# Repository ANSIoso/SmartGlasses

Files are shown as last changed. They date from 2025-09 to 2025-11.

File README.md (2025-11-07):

# SmartGlasses
Simple prototype of AR glasses inspired to Dragon Ball scouter and powered by Esp32 - cam and YOLO11
<p align="center"  style="display: flex; gap: 50px; justify-content: center;">
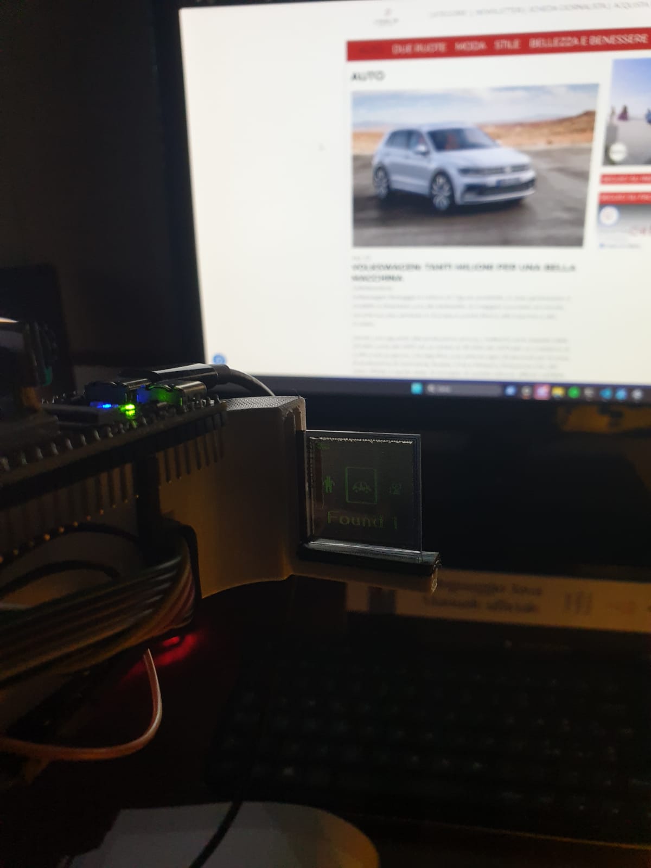
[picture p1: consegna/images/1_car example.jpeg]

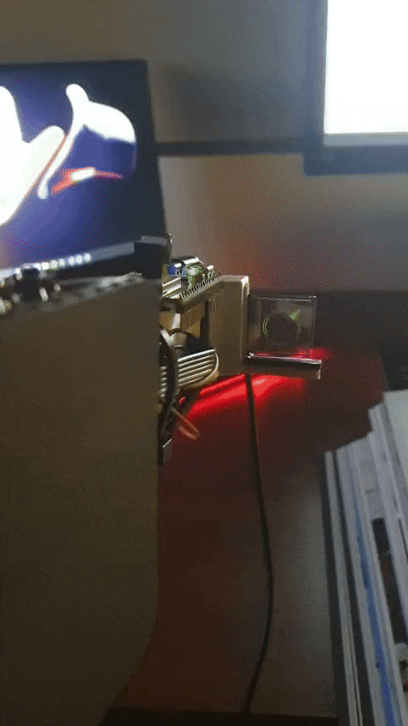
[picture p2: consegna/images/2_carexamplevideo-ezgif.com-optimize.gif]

</p>

<p align="center">
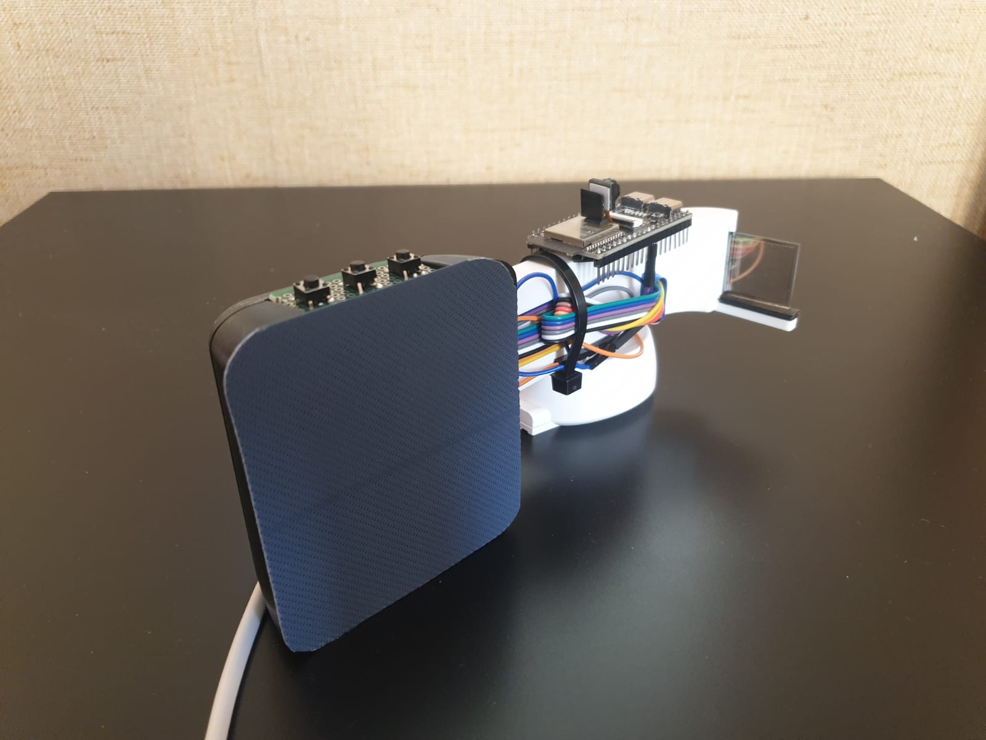
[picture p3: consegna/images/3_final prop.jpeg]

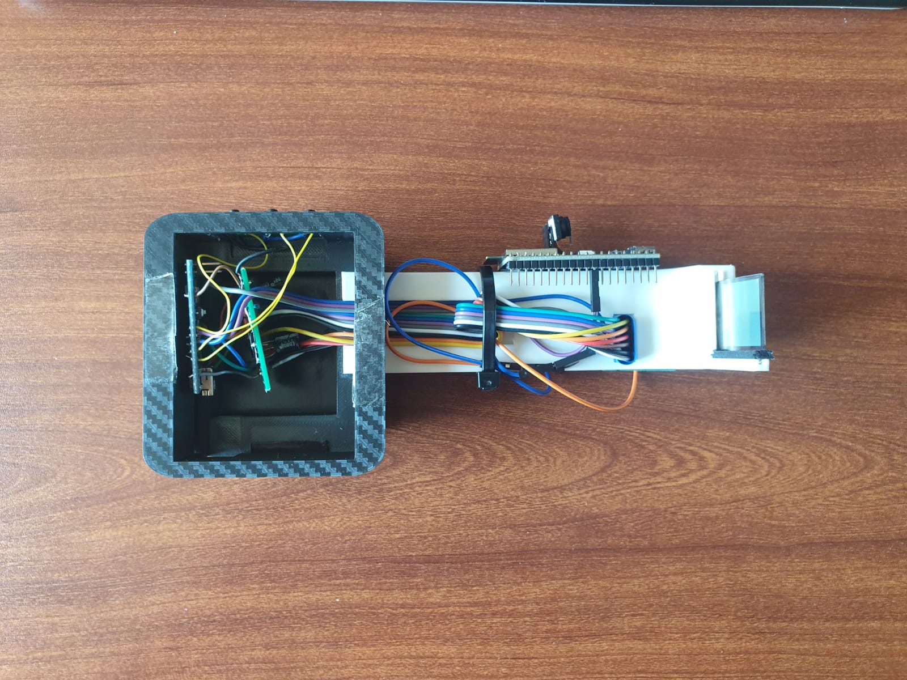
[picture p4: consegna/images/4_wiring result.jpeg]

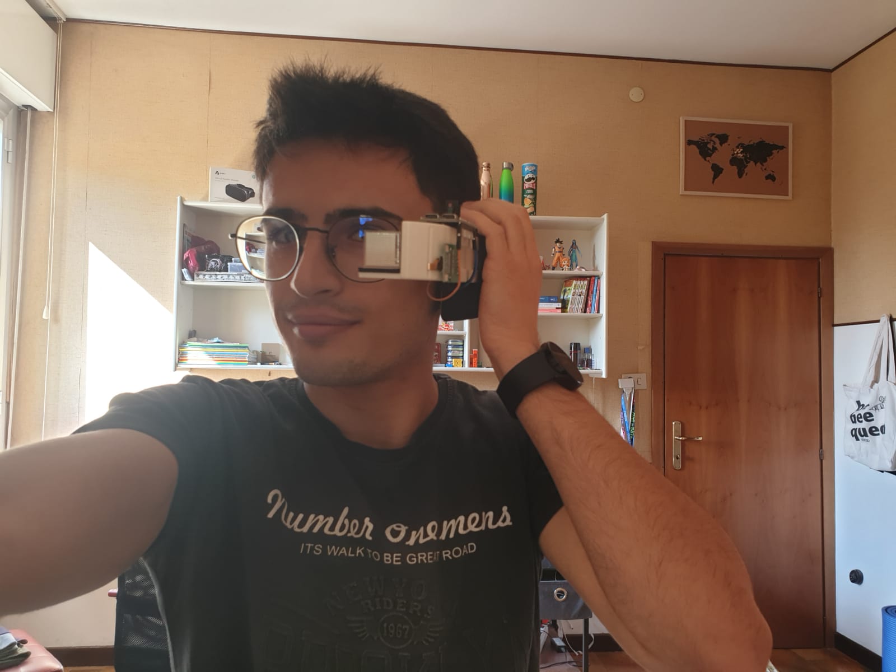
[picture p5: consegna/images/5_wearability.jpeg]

</p>

## Requirements

- hardware
    - [ESP32-S3 WROOM N16R8 CAM](https://it.aliexpress.com/item/1005007308040075.html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)
    - [Arduino Nano 3.0](https://it.aliexpress.com/item/1005008505441191.html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)
    - [Transparent OLED Display](https://it.aliexpress.com/item/1005007983700262.html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)
    - Your PC

- software requirements
    - [ultralitics yolo11](https://docs.ultralytics.com/quickstart/)
    - [ArduinoJson](https://arduinojson.org/v6/doc/installation/)
    - [U8g2lib](https://github.com/olikraus/u8g2/wiki/u8g2install)

## how it works

<p><strong>Pipeline</strong></p>

The sistem uses 3 distict elements to work, the ESP32 who capture the image and coordinate all the operations, the pc who process the image recevived by the esp32 using the yolo11 model and pacs the information about the received object for a easier use in the rest of the pipeline and the arduino nano that takes the info received and display it in the trasparent dispaly.

<p align="center">
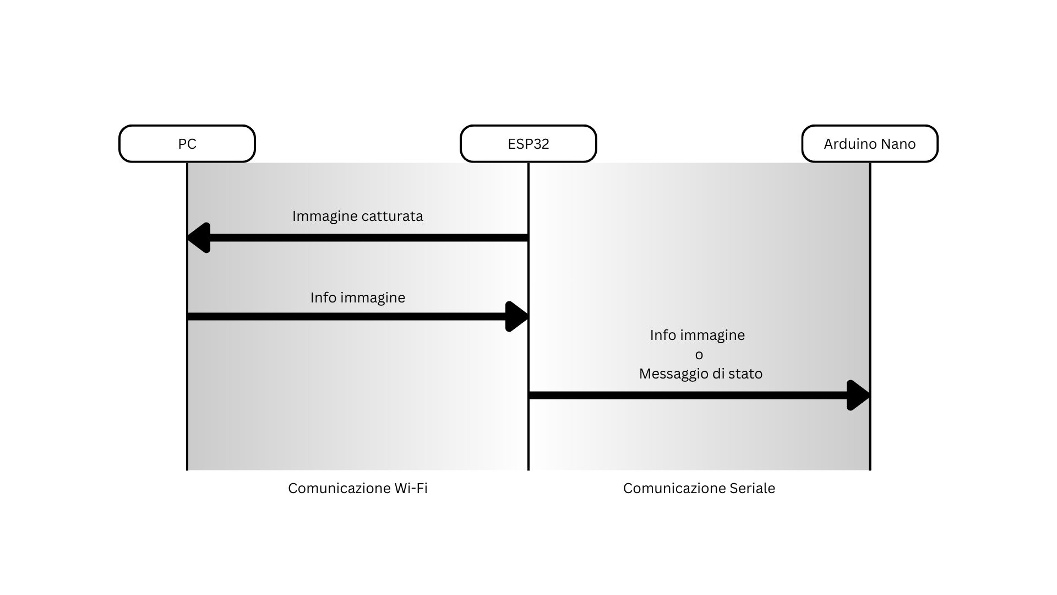
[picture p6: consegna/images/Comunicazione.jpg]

</p>

<p><strong>Interface</strong></p>

The information about the detected object is shown on the trasparent screeen, is possible to visualize the information in two different format:
- the **count view** that show the selected object category and the number of occorrence 
- the **radar view** that show the position of the detected objects for the selected category

<p align="center" style="display: flex; gap: 50px; justify-content: center;">
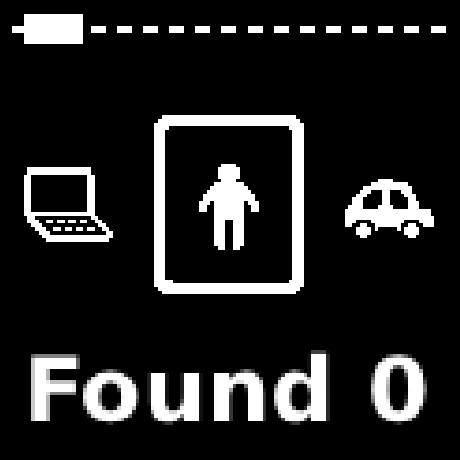
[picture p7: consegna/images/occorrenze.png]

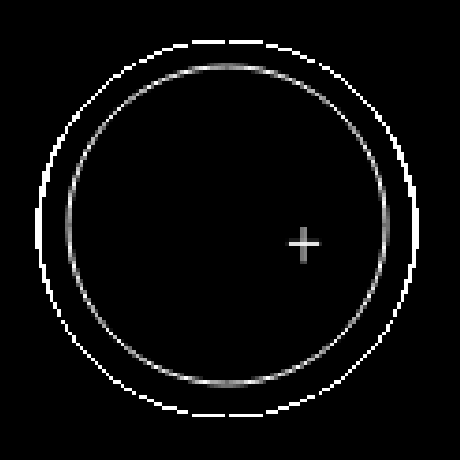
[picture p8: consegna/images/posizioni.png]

</p>

In order to create the radar view the detected position are first converted to the size of the screen, then to add the arrow effect the distance from the center of the screen is calculated, if the resulting distance is greeater than a certain tresholde the position are scomposed to sin and cos respect a reference sistem positioned in the center of the screen, this are used to find the angle at wich dispaly the arrow

Two of the buttons on the device are used to go back and forth betwen the category and the other to swithch betwen the views
<p align="center">
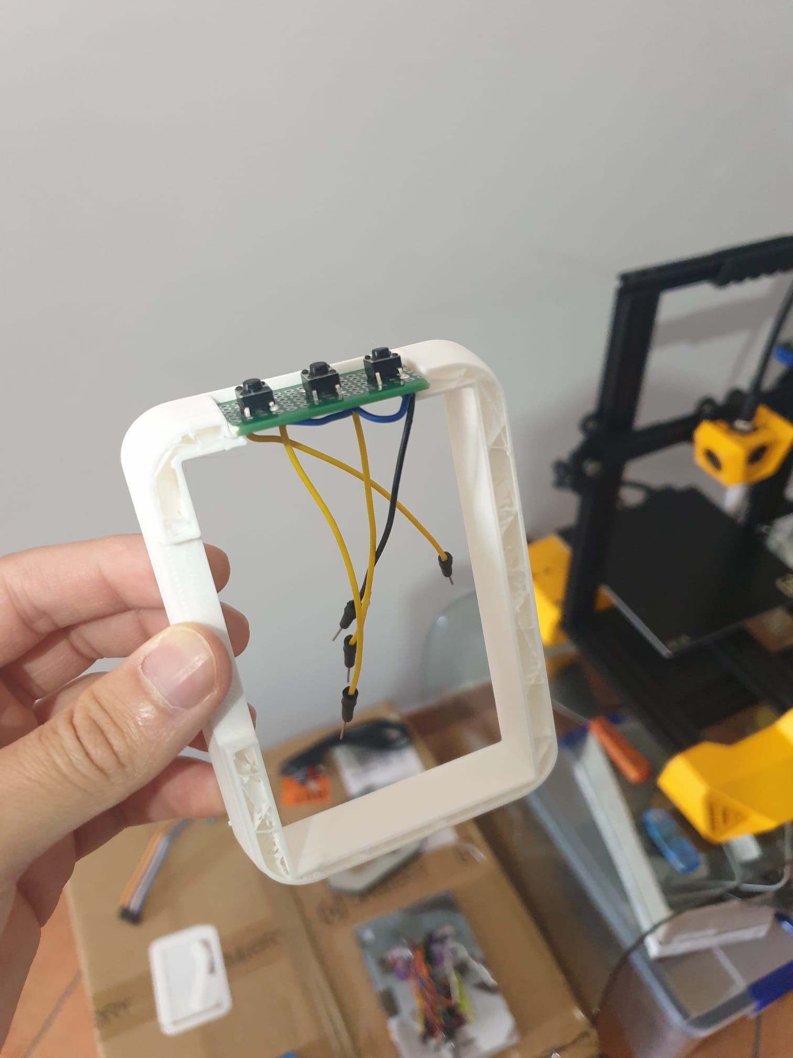
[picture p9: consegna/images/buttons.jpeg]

</p>

## Wiring
<p align="center">
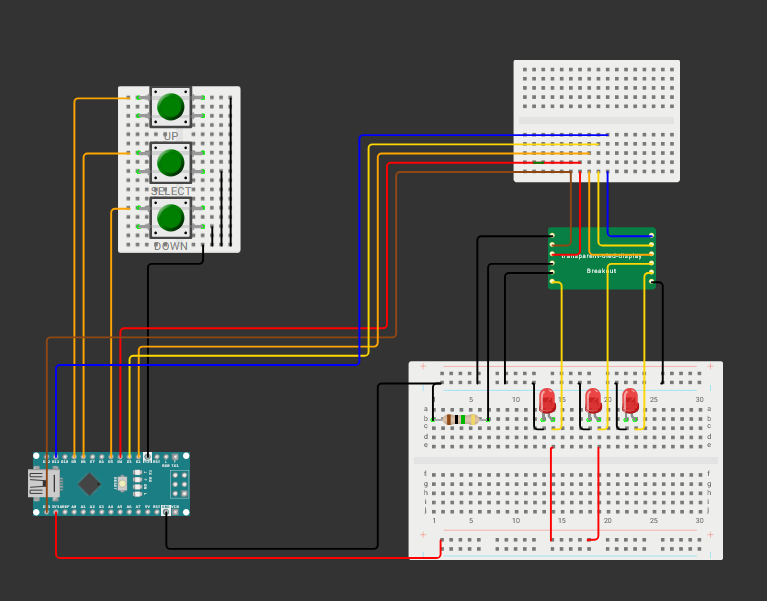
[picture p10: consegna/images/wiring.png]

</p>

For detailed wiring of the display board, refer to the [official screen documentation](https://surenoo.tech/download/03_SOL/0302_SOG/SOG128128A_T112.pdf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) (note: the LEDs in the schematic represent 10㎌ 50V capacitors).

To complete the circuit, establish serial communication between the Arduino and ESP32:
- Connect the grounds between the two boards
- Connect RX to TX (pin 6 on Arduino, pin 1 on ESP32)
- Connect TX to RX (pin 7 on Arduino, pin 3 on ESP32)

## 3D print

All the components are contained in a case to emulate the famus Scouter from Dragon Ball Z, to reproduce it I started from [this model 3D model](https://www.thingiverse.com/thing:2853831) that i found online and edited it in fusion 360 to make room for all the components. The result models are contained in the folder [glasses_assets/3D model](./glasses_assets/3D%20model/)

- [Asta.stl](./glasses_assets/3D%20model/Asta.stl) that holds the trasparent dispaly and the ESP32
- [Coperchio.stl](./glasses_assets/3D%20model/Coperchio.stl) that contains the Arduino Nano and the display board
- [Padiglione.stl](./glasses_assets/3D%20model/Padiglione.stl) that holds the buttons

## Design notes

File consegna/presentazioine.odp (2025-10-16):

## Scouter DAI

Augmented Reality Glasses

## Obiettivi del Progetto

  Sviluppare un dispositivo :
  - Indossabile e autonomo
  - Capace di analizzare l’ambiente circostante in tempo reale
  - Il cui restituisce informazioni utili e contestuali direttamente all’utente

## Ispirazione Scouter DAI

- Dispositivo indossabile
- Analisi in tempo reale di ciò che si ha di fronte, per supportare l’utente
- Informazioni visive tramite display trasparente

## Architettura del Dispositivo AR

- Acquisizione dati:
  estrapolazione di informazioni dall’ambiente tramite
- Visualizzazione:
  proiezione su schermo trasparente

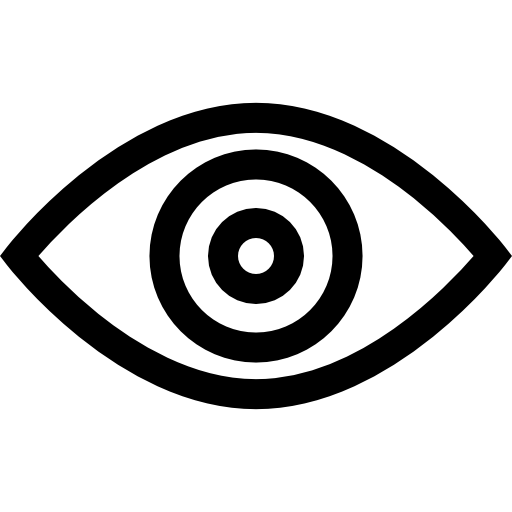
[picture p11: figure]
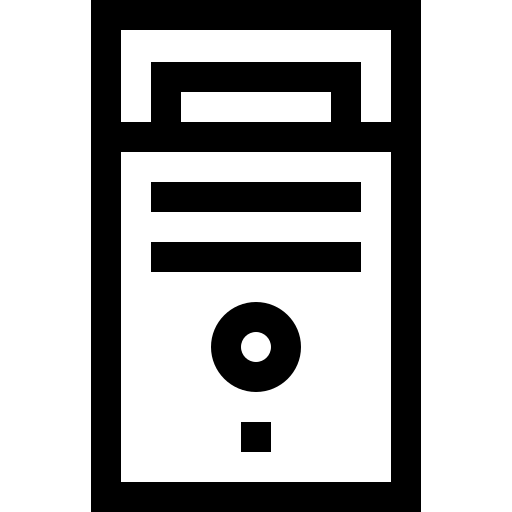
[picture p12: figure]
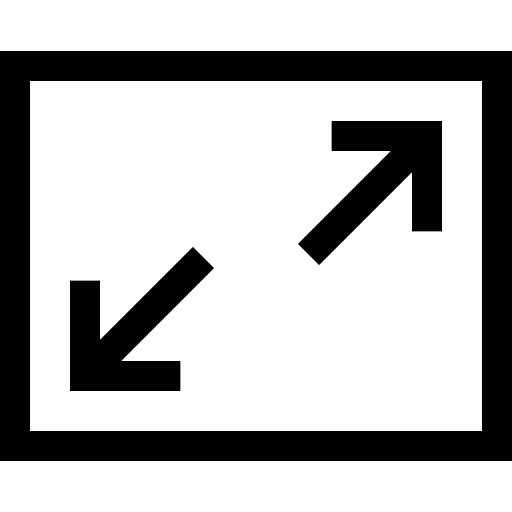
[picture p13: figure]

- Elaborazione:
  analisi delle immagini

## Analisi delle Immagini

  L’analisi delle immagini viene realizzata tramite tecniche di object detection
- Approccio Edge:
  - Esecuzione direttamente sul dispositivo
  - Librerie: Edge Impulse, TensorFlow Lite
- Approccio Client-Server:
  - Elaborazione delle immagini su “supporti” esterni
  - Modelli avanzati: Faster R-CNN, YOLO v11

## Pipeline Elaborazione AR

1) Acquisizione:

l’ESP32-CAM cattura singole immagini

2) Trasmissione:

invio delle immagini al PC tramite HTTP

3) Elaborazione:

il PC analizza le immagini con YOLO v11 individua oggetti e categorie

4) Restituzione dati:

il PC invia i risultati in formato JSON all’ESP32

5) Comunicazione interna:

l’ESP32 condivide i dati con l’Arduino Nano tramite seriale

6) Visualizzazione:

l’Arduino mostra a schermo la posizione degli oggetti rilevati

## Hardware Utilizzato

  Il sistema integra dispositivi eterogenei, ognuno con un ruolo specifico
- ESP32-S3 WROOM N16R8 CAM
  - Raccolta delle immagini dall’ambiente
  - Coordinamento e arbitraggio tra i componenti
- Arduino Nano 3.0
  - Visualizzazione delle informazioni sullo schermo trasparente
  - Gestione Input tasti
- PC
  - Elaborazione delle immagini tramite modelli di Object Detection

## Hardware Utilizzato

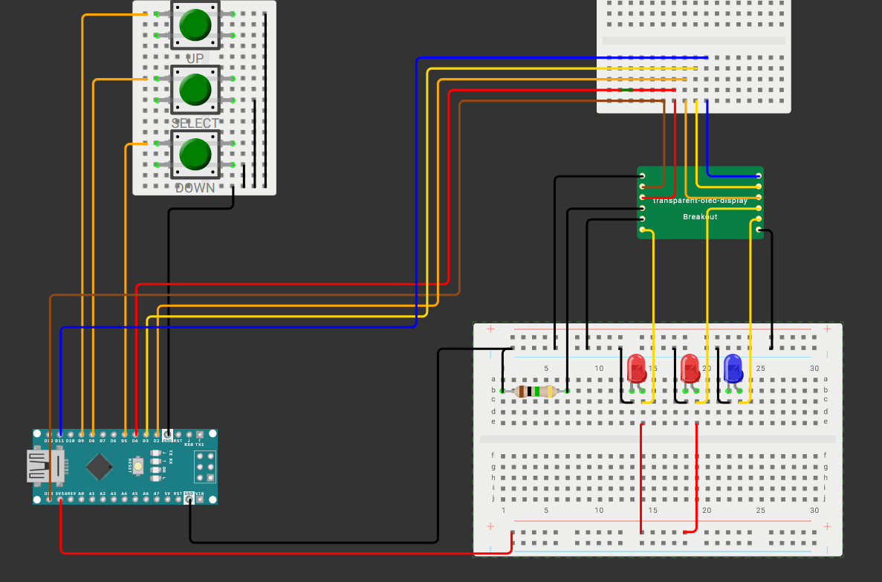
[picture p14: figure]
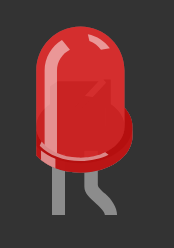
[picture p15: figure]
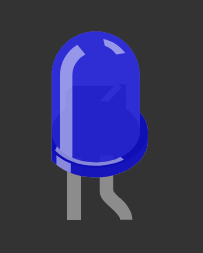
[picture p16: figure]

Condensatore

Condensatore

Resistenza

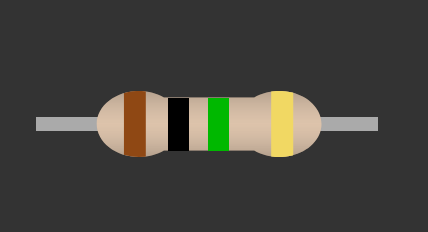
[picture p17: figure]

## Assemblaggio

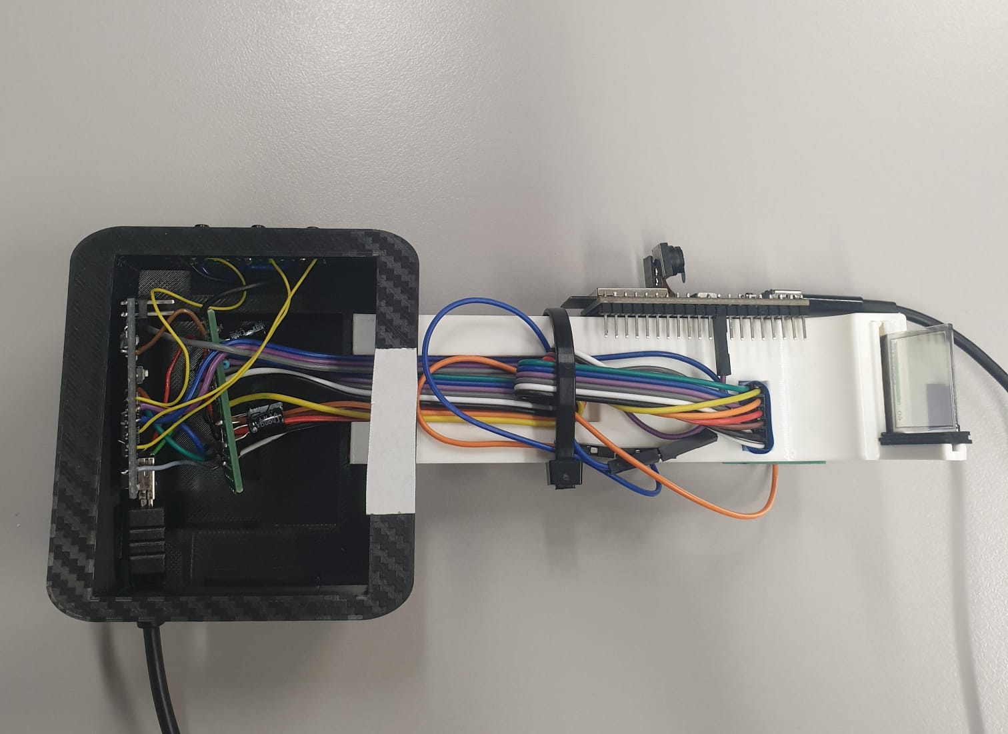
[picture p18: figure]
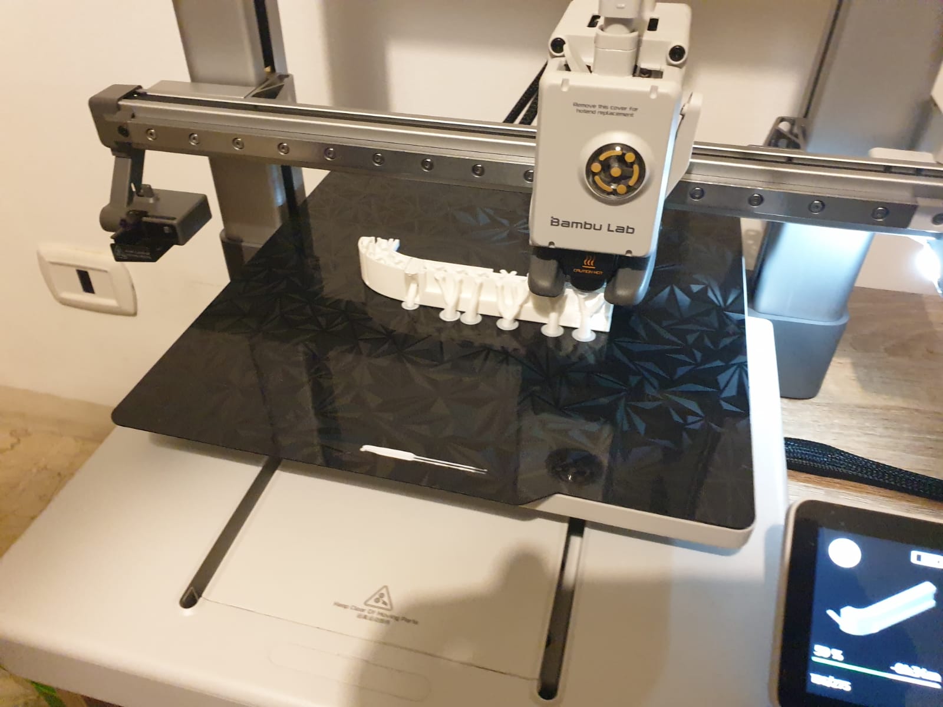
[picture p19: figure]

Condensatore

Condensatore

Resistenza

## Elaborazione Immagini

Object Detection Effettuata

con YOLO v11

Comunicazione ESP32 ↔ PC:

- ESP32 → invio tramite HTTPClient
- PC → gestione richieste con Flask

Debug e visualizzazione dei risultati tramite OpenCV (cv2)

## Visualizzazione Informazioni

La pipeline di visualizzazione traduce i dati elaborati in informazioni grafiche comprensibili e immediatamente fruibili dall’utente.

I dati in formato JSON ricevuti dall’ESP32 vengono inviati ad Arduino Nano tramite comunicazione seriale

L’Arduino spacchetta i dati e li mostra sullo schermo trasparente

Visualizzazione implementata con:

- ArduinoJson → parsing dei dati
- U8g2 → gestione delle primitive grafiche e bitmap

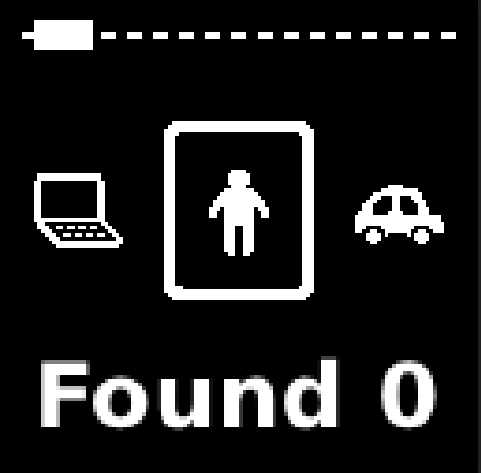
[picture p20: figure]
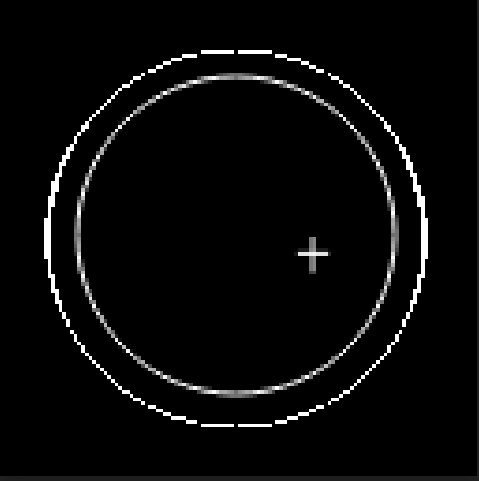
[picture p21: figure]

## Problemi Riscontrati (Schede)

- Compatibilità ESP32-S3 CAM
  - Complessità utilizzo libreria U8g2
  - Problemi con alcune librerie di Machine Learning (Edge Impulse)
- Capienza Arduino Nano
  - Memoria limitata per gestione dei dati e visualizzazione
- Latenza del sistema
  - Tempi di cattura della camera
  - Comunicazione con il server per l’elaborazione

## Problemi Riscontrati (Display)

- Disponibilità delle informazioni:
  - Gestione del wiring tra componenti
  - Utilizzo corretto delle librerie per parsing e rendering dei dati
- Visualizzazione delle informazioni:
  - Alta densità di informazioni su schermo di piccole dimensioni
  - Problemi di messa a fuoco dovuti alla distanza dagli occhi

## Pro e Contro del Sistema

Il sistema offre grande flessibilità, ma richiede compromessi su performance e visualizzazione.

- Pro modularità:
  - Possibilità di sostituire modelli di analisi e interfacce utente
  - Flessibilità nella rappresentazione dei dati all’utente
- Contro:
  - Tempi di latenza dovuti a acquisizione immagini e comunicazione con server
  - Dimensioni totali

## Conclusioni

Il progetto offre una base solida per dispositivi AR indossabili, con margini di miglioramento per portabilità e ottimizzazione hardware.

Possibili sviluppi futuri:

- Ridurre le dimensioni complessive utilizzando schede dedicate
- Spostare l’elaborazione per aumentare la portabilità:
  - Su smartphone
  - Su edge devices

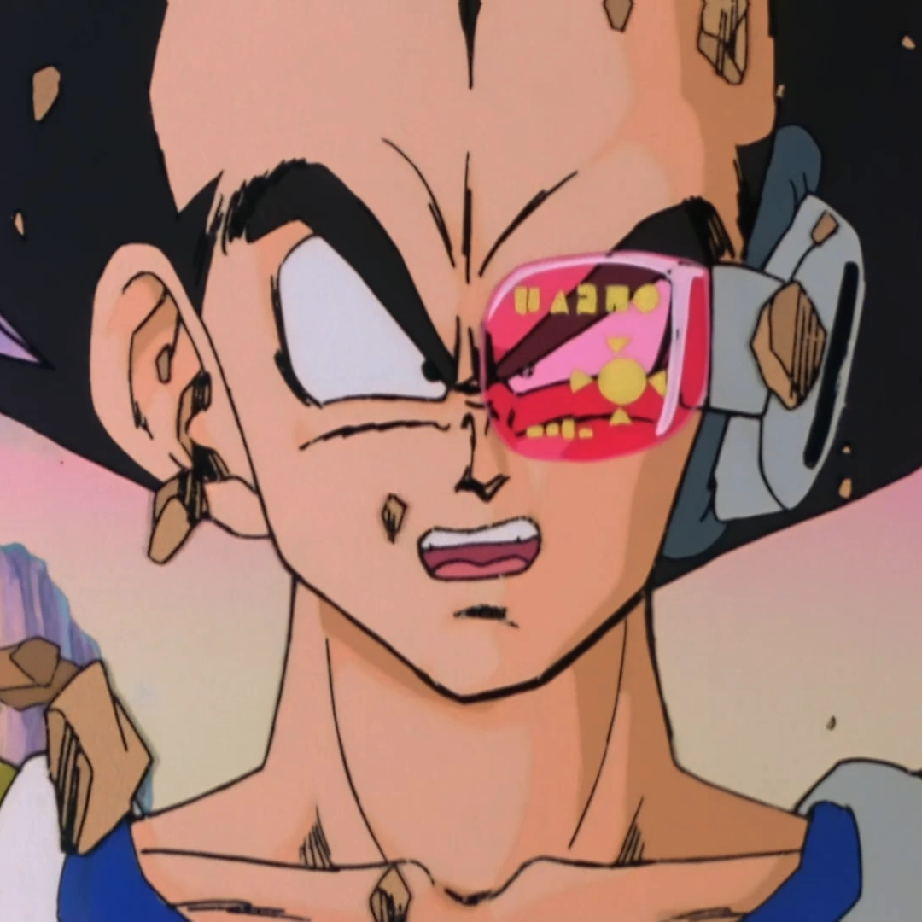
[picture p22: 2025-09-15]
consegna/images/Scouter_Reference.png

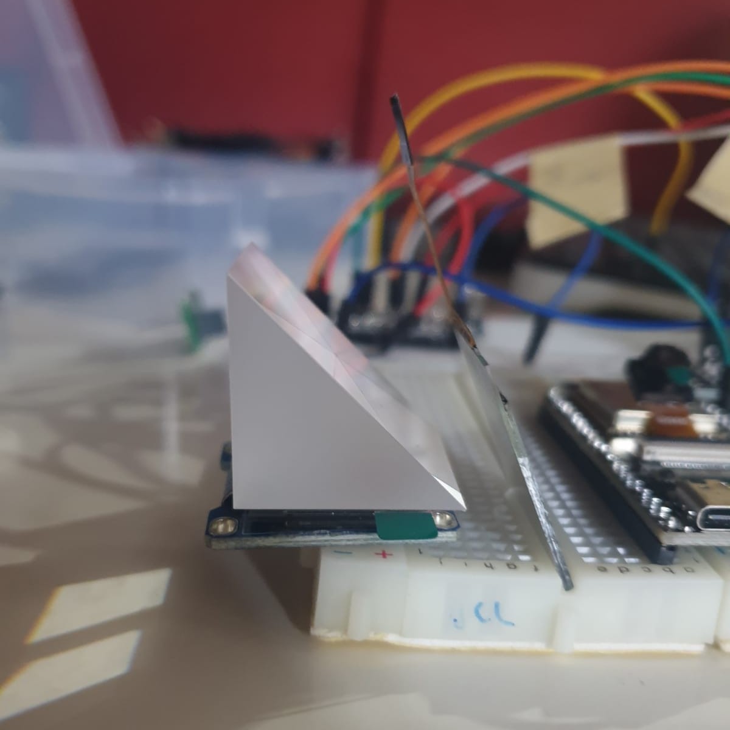
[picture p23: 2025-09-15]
consegna/images/screen_comp1.jpeg

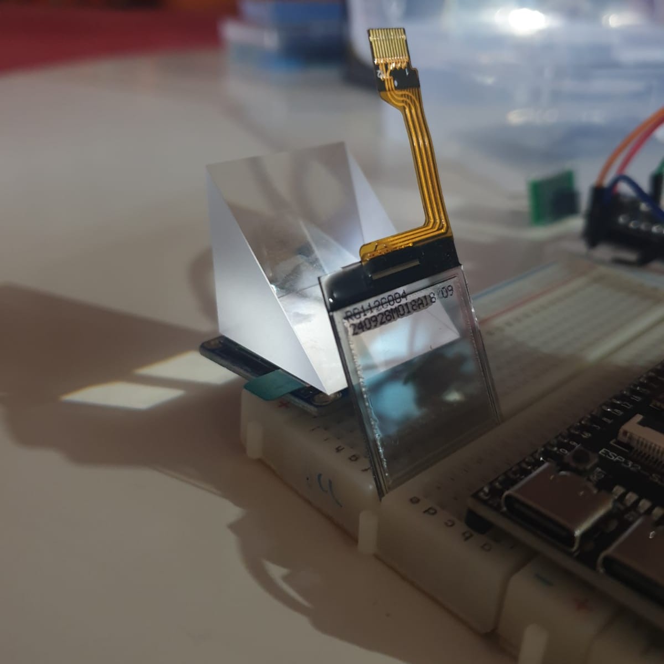
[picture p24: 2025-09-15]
consegna/images/screen_comp2.jpeg

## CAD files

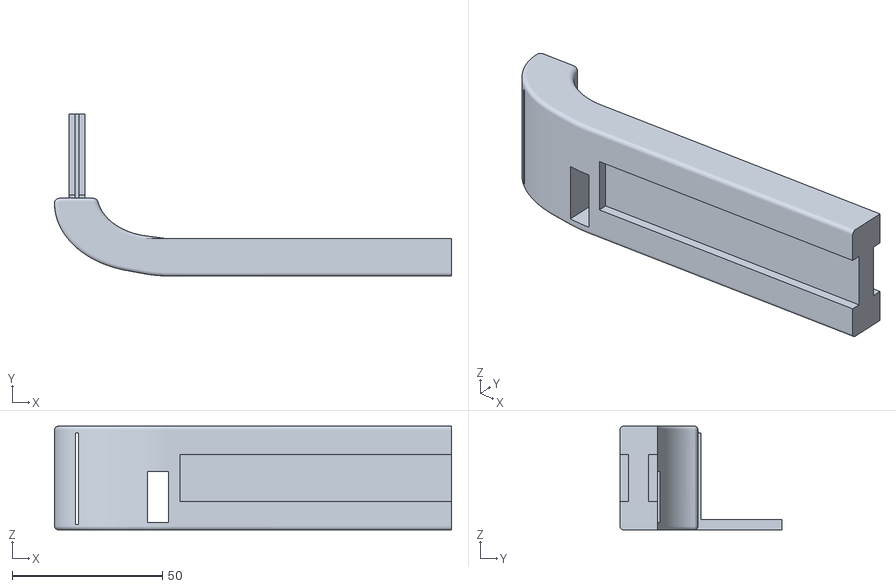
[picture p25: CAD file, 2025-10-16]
glasses_assets/3D model/Asta.stl
132.2 x 53.9 x 34.6

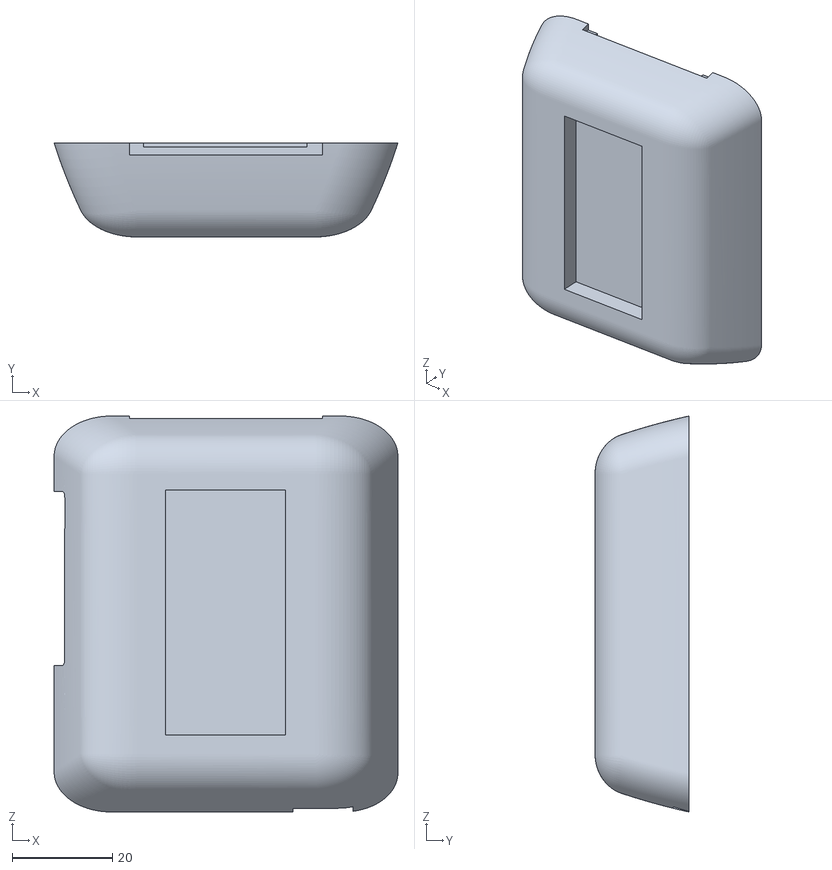
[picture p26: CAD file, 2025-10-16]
glasses_assets/3D model/Coperchio.stl
68.5 x 18.7 x 78.9

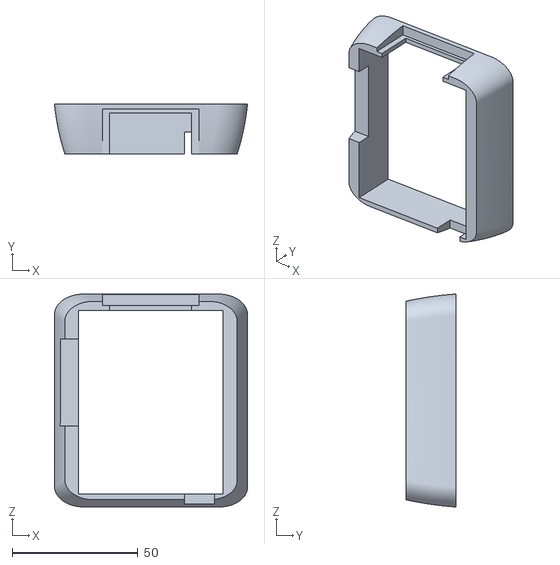
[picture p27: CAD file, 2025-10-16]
glasses_assets/3D model/Padiglione.stl
76.7 x 19.9 x 84.6

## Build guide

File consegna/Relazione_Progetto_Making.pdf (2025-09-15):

# Relazione Progetto Making

Antonio Sisinni

Septembre 2025

## 1 Introduzione

L’obiettivo del progetto `e quello di mettere in pratica le conoscenze acquisite durante le lezioni, in particolare riguardo a:

- schede programmabili
- sensori e interruttori
- circuiti elettrici
- stampa 3D

Tali competenze devono essere applicate per realizzare un prototipo funzionante, in grado di svolgere un compito da noi definito.

## 2 Idea

L’idea alla base del progetto consiste nello sviluppo di un dispositivo in grado di integrare diverse tecnologie affrontate a lezione, con l’aggiunta di elementi di interesse personale. A tale scopo ho deciso di realizzare un dispositivo indossabile per la realt`a aumentata.

Il sistema prevede l’impiego di una telecamera per acquisire informazioni dall’ambiente circostante. I dati raccolti vengono elaborati e successivamente presentati all’utente tramite un display trasparente, cos`ı da non compromettere la visibilit`a diretta.

L’interazione con il dispositivo `e resa possibile attraverso dei pulsanti che consentono all’utente di filtrare o modificare le informazioni visualizzate.

Data la necessit`a di includere pi`u componenti hardware, il design di riferimento scelto `e lo scouter della serie Dragon Ball. Esso presenta dimensioni adeguate per ospitare i vari elementi, garantendo al contempo una buona ergonomia.

1

## 3 Studio di fattibilit`a

### 3.1 Schermo trasparente

In un primo momento avevo pensato di utilizzare un normale schermo abbinato a un prisma ottico, cos`ı da ridirezionare l’immagine e permettere all’utente di guardare attraverso.

Sebbene questa soluzione fosse funzionale, l’ingombro complessivo e il peso derivante dall’accoppiata schermo + prisma mi hanno spinto a optare per l’utilizzo di un display trasparente Figura 1.

Questa scelta, tuttavia, ha introdotto una nuova difficolt`a: la libreria u8g2 (utilizzata per disegnare sul display), il mio specifico display e la scheda ESP32-S3, non risultavano funzionanti assieme.

Per superare questo problema ho adottato una configurazione ibrida: la ESP32-S3 per la potenza di elaborazione, affiancata da un Arduino Nano dedicato esclusivamente alla gestione della visualizzazione sul display.


Figure 1: Confronto ingombri tra le due soluzioni per il display schermo

### 3.2 Elaborazione delle immagini

La mia idea iniziale era di sfruttare direttamente la ESP32-S3 per l’elaborazione delle immagini, in quanto dotata di capacit`a di calcolo sufficienti a supportare modelli di machine learning leggeri (soluzioni come edgeimpulse o tensorflow lite nascono proprio per dispositivi del genere).

Tuttavia, la scheda da me acquistata presentava scarsa documentazione e non aveva compatibilit`a diretta con librerie apposite. Dopo alcuni tentativi ho quindi

2

deciso di utilizzare la ESP32-S3 unicamente la cattura dei dati e la trasmissione di essi via Wi-Fi, demandando l’elaborazione delle immagini a un dispositivo esterno. In questo modo ho potuto ottenere le informazioni necessarie mantenendo il dispositivo portatile.

## 4 Struttura del Sistema

Le diverse parti del sistema collaborano per assolvere compiti distinti, cos`ı da garantire il corretto funzionamento complessivo e la fruibilit`a da parte dell’utente.

- ESP32-s3 cuore del sistema, si occupa di acquisire le immagini e di gestire la comunicazione tra le varie componenti
- Arduino Nano gestisce il display OLED trasparente sul quale l’utente visualizza le informazioni elaborate. Inoltre, si occupa dell’acquisizione degli input dell’utente
- Un PC `e usato come dispositivo esterno per eseguire l’elaborazione delle immagini tramite il modello di computer vision YOLOv11, che consente di individuare all’interno di immagini oggetti presenti, identificandone posizione e classe di appartenenza.

## 5 Pipeline di Comunicazione

Affinch´e il sistema possa operare correttamente, le diverse componenti devono comunicare tra loro. La struttura della comunicazione `e illustrata in Figura 2.

La connessione tra l’esp32-s3 e il PC avviene in modalit`a wireless, cos`ı da garantire la mobilit`a dell’utente. La comunicazione tra l’esp32-s3 e l’Arduino Nano, invece, utilizza un semplice collegamento seriale, per garantire bassa latenza.

### 5.1 Messaggi di Stato

Oltre a trasmettere le informazioni relative alle immagini acquisite, l’esp32-s3 pu`o inviare una serie di messaggi sullo stato del sistema. Questi messaggi risultano particolarmente utili per informare l’utente sul corretto funzionamento del dispositivo, soprattutto in caso di malfunzionamenti nella trasmissione dei dati.

I messaggi di stato previsti sono:

- connecting: indica che il dispositivo sta tentando di stabilire la connessione con il PC
- com err: segnala un problema di comunicazione tra l’esp32-s3 e il PC

3


Figure 2: Schema della pipeline di comunicazione tra le componenti del sistema.

## 6 Hardware Utilizzato

### 6.1 Componenti

Per la realizzazione del prototipo ho utilizzato i seguenti componenti:

- ESP32-S3 WROOM N16R8 CAM (https://it.aliexpress.com/item/1005007308040075.html)
- Arduino Nano 3.0 (https://it.aliexpress.com/item/1005008505441191.html)
- Display OLED Trasparente (https://it.aliexpress.com/item/1005007983700262.html)
- Resistenza
Valore: 1 MΩ ± 1%
- Condensatori
Tre unit`a (la tipologia precisa verr`a specificata successivamente).
- Pulsanti
Tre unit`a, utilizzati come input utente.

### 6.2 Wiring

Lo schema di collegamento dei componenti `e mostrato in Figura 3. Nel diagramma, i LED rappresentano simbolicamente i condensatori utilizzati nel circuito.
La esp32-s3 `e poi collegata ad Arduino Nano tramite connessione seriale.

4


Figure 3: Schema di collegamento (wiring) dei componenti del sistema.

## 7 Elaborazione delle Immagini

Per ottenere informazioni sull’ambiente circostante utilizzo la fotocamera integrata nella ESP32-S3. Le immagini acquisite devono essere analizzate per estrarne i dati utili.

### 7.1 Cattura

Per la gestione della fotocamera faccio uso della libreria esp camera.h, che mette a disposizione la funzione:

camera fb t * fb = esp camera fb get();

Tale funzione permette di catturare un frame (fb) che viene poi inviato per l’analisi tramite una HTTP request, realizzata con la libreria HTTPClient.h.

Per garantire un buon compromesso tra frequenza di acquisizione e qualit`a delle catture, ho utilizzato i seguenti parametri per la camera:

- frame size = FRAMESIZE VGA
- jpeg quality = 15

5

### 7.2 Analisi

L’analisi delle immagini `e affidata al modello di computer vision YOLOv11, che individua all’interno del frame gli oggetti presenti, specificandone posizione e classe di appartenenza.

Le informazioni estratte vengono poi impacchettate e inviate nuovamente alla ESP32-S3 come risposta. In questa fase la comunicazione `e gestita da un server Flask, che riceve le immagini, le elabora e restituisce i risultati in formato strutturato.

## 8 Interazione Utente

Il sistema `e progettato per interagire in modo bidirezionale con l’utente.

### 8.1 Sistema → Utente

L’utente pu`o visualizzare sul display trasparente le informazioni relative alle classi di oggetti selezionate. Per ciascuna classe mostro:

- il numero di occorrenze rilevate (Figure 4a);
- la posizione degli oggetti individuati all’interno dell’immagine (Figure 4b).

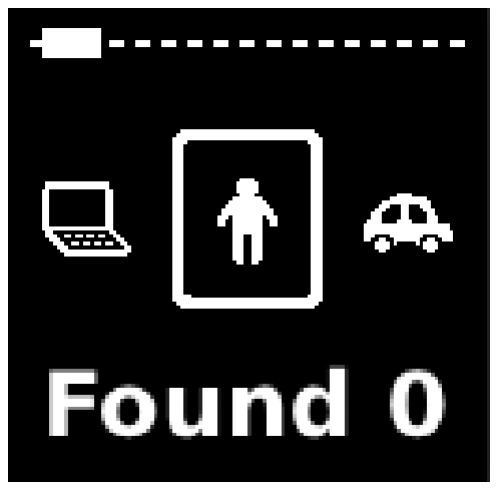
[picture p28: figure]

(a) Modalit`a Conteggio mostra il numero di occorrenze per ciascuna classe.


(b) Modalit`a Localizzazione mostra posizione degli oggetti individuati.

Per la creazione dell’interfaccia ho utilizzato la libreria u8g2, essa mette a disposizione primitive grafiche per il disegno su display e la possibilit`a di caricare e utilizzare bitmap per rappresentare elementi pi`u complessi.

6

### 8.2 Utente → Sistema

L’utente interagisce con il dispositivo tramite i tre pulsanti integrati. In particolare, pu`o:

- navigare tra le diverse classi disponibili (tasti su e gi`u)
- passare da modalit`a conteggio modalit`a localizzazione (tato select)

## 9 Difficolt`a

Lo sviluppo di questo progetto ha presentato diverse difficolt`a che mi hanno richiesto tempo e sperimentazione per essere affrontate.

### 9.1 Utilizzo della ESP32-S3 CAM

Ho incontrato problemi di compatibilit`a con i modelli di elaborazione delle immagini in esecuzione su dispositivi edge, oltre a difficolt`a legate all’integrazione con il display trasparente (come gi`a descritto nello studio di fattibilit`a).

### 9.2 Memoria insufficiente di Arduino Nano

La memoria ridotta della scheda ha limitato la complessit`a dell’interfaccia utente che potevo sviluppare. Questo problema potrebbe essere in parte risolto distribuendo meglio i compiti tra la ESP32-S3 e l’Arduino Nano.

### 9.3 OLED Display Trasparente

L’assenza di una documentazione estesa ha reso complesso sia l’utilizzo sia il collegamento del display. Inoltre, le sue particolari caratteristiche tecniche hanno richiesto numerosi tentativi di configurazione.

### 9.4 Problemi ottici con il display

Ho dovuto calibrare attentamente la distanza del display dall’occhio e regolare la dimensione dei caratteri, cos`ı da ottenere una leggibilit`a adeguata e ridurre l’affaticamento visivo.

7

## 10 Peculiarit`a

Il progetto ha una struttura molto modulare, che mi permette di sostituire facilmente le sue componenti principali.

- Modelli di analisi
Posso sostituire il modello di elaborazione delle immagini per ottenere prestazioni migliori o per estrarre informazioni differenti in base all’applicazione.
- Interfaccia utente
L’attuale interfaccia basata su display pu`o essere sostituita con altri sistemi di output, come ad esempio un’interfaccia audio, utile per supportare utenti non vedenti nella navigazione dell’ambiente.

## 11 Conclusioni

Il progetto offre una base solida per dispositivi AR indossabili, con ampi margini di miglioramento per quanto riguarda portabilit`a e ottimizzazione hardware.

Possibili sviluppi futuri:

- Ridurre le dimensioni complessive mediante schede dedicate per la gestione dei pulsanti e la connessione del display
- Spostare l’elaborazione delle immagini aumentare la portabilit`a, ad esempio:

– su smartphone
– su dispositivi edge (utilizzando Edge Impulse o TensorFlow Lite)

## 12 Reference

1. connessione scehermo SPI (https://wiki.seeedstudio.com/Grove-OLED-Display-1.12-SH1107_V3.0/)
2. modelli elaborazione immagini edge (https://www.youtube.com/watch?v=ILh38jd0GNU)
3. modello elaborazione immagini PC (https://docs.ultralytics.com/models/yolo11/)
4. comunicazione seriale (https://theorycircuit.com/esp32-projects/arduino-and-esp32-serial-data-communication-setup/)
5. cablaggio schermo (https://surenoo.tech/download/03_SOL/0302_SOG/SOG128128A_T112.pdf?file=SOG128128A_T112.pdf)
6. utilizzo bitmap 1 (https://www.youtube.com/watch?v=HVHVkKt-ldc&t=883s) 2 (https://javl.github.io/image2cpp/)

8

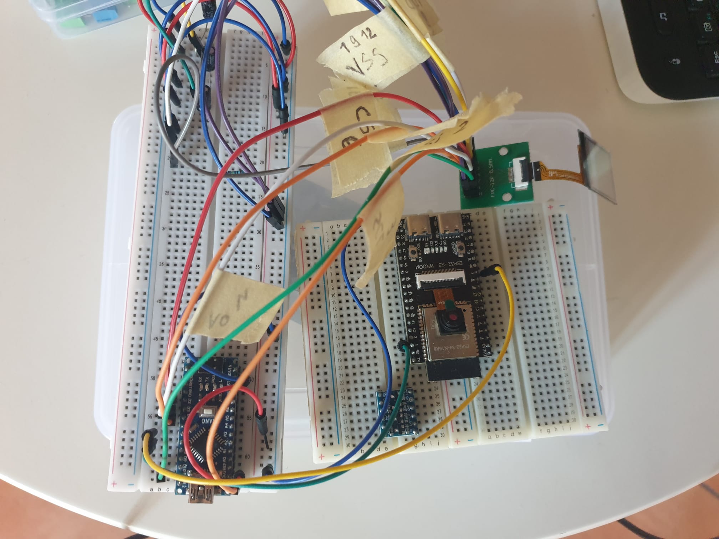
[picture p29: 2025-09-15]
consegna/images/board_wiring.jpeg

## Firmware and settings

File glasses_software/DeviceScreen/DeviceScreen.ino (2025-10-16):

#include <Arduino.h>
#include <U8g2lib.h>
#include <SPI.h>
#include <Wire.h>

#include <ArduinoJson.h>
#include <SoftwareSerial.h>

#include "MenuLogic.h"
#include "MenuView.h"


// ====== COMUNICATION ======
// file stream
SoftwareSerial mySerial(6, 7); // RX, TX
String data;
JsonDocument doc;
// baud rate info
# define BR_COMUNICATION 9600 // to talk with esp32
# define BR_DEBUG 57600       // to check device outputs

// ====== VISUALIZATION ======
U8G2_SH1107_PIMORONI_128X128_1_4W_HW_SPI u8g2(U8G2_R3, /* cs=*/A2, /* dc=*/A3, /* reset=*/A4);
// image settings
# define IMG_HEIGHT 480
# define IMG_WIDTH 640
// screen settings
# define SCREEN_HEIGHT 128
# define SCREEN_WIDTH 128

// ====== NAVIGATION ======
// logic
MenuLogic screenMenuL(MenuBitmaps::ICON_COUNT);
int up_btn_clicked = 0;
int menu_btn_clicked = 0;
int down_btn_clicked = 0;
// buttons pins
#define BUTTON_UP 9
#define BUTTON_SELECT 5
#define BUTTON_DOWN 8



void setup() {
  mySerial.begin(BR_COMUNICATION);
  Serial.begin(BR_DEBUG);
  
  // Initialize SPI pins
  u8x8_t *u8x8 = u8g2.getU8x8();
  u8x8->pins[U8X8_PIN_SPI_CLOCK] = SCK;
  u8x8->pins[U8X8_PIN_SPI_DATA] = MOSI;
  
  Wire.begin();
  u8g2.begin();
  
  pinMode(BUTTON_UP, INPUT_PULLUP);
  pinMode(BUTTON_SELECT, INPUT_PULLUP);
  pinMode(BUTTON_DOWN, INPUT_PULLUP);
}

void loop() {

  // ---- handle menù navigation (via buttons) ----
  if((menu_btn_clicked == 0) && (digitalRead(BUTTON_SELECT) == LOW)){
		screenMenuL.toggleMenu();
		menu_btn_clicked = 1;
	}
	if((menu_btn_clicked == 1) && (digitalRead(BUTTON_SELECT) == HIGH)){
		menu_btn_clicked = 0;
	}
	

  if((up_btn_clicked == 0) && (digitalRead(BUTTON_UP) == LOW)){
    screenMenuL.nextItem();
    up_btn_clicked = 1;
  }
  if((up_btn_clicked == 1) && (digitalRead(BUTTON_UP) == HIGH)){
		up_btn_clicked = 0;
	}


  if((down_btn_clicked == 0) && (digitalRead(BUTTON_DOWN) == LOW)){
    screenMenuL.previousItem();
    down_btn_clicked = 1;
  }
  if((down_btn_clicked == 1) && (digitalRead(BUTTON_DOWN) == HIGH)){
		down_btn_clicked = 0;
	}

  // ---- handle comunication with esp ----  
  String status = getObjs();
  //Serial.println(status);
  if(status == "s_empty"){
    return;
  }
  if(status != "s_ok"){
    DrawStatus(status);
    return;
  }

  // ---- handle screen visualizzation ----
	if(screenMenuL.isMenuActive())
    DrawMenu();
  else
    VisualizeObjects();
}

// ======== OBJ UTILS ========
String getObjs(){
  // check if there are data available to receive from esp
  if (!mySerial.available())
    return "s_empty";

  // if available get the data
  data = mySerial.readStringUntil('\n');
  data.trim();

  // if data are not useful return error
  if (data == "")
    return "s_empty";


  if (data == "connect" || data == "com_err")
    return data;

  // convert the data string in a json file to access to single elements
  DeserializationError error = deserializeJson(doc, data);
  if (error != DeserializationError::Ok)
    return "s_empty";

  // if all went good return success
  return "s_ok";
}

int CountClassObjects(char className[]){
  int objCount = 0;

  // going for all the found objects
  for(int i = 0; i < doc.size(); i++) {
    JsonObject obj = doc[i];
    
    // count all the istances of the specified class
    if(obj["class"] == className)
      objCount++;
  }

  return objCount;
}

// ======== DRAWING METODS ========
void VisualizeObjects(){  
  const int screenCenterX = SCREEN_WIDTH / 2;   
  const int screenCenterY = SCREEN_HEIGHT / 2;  
  const int radarRadius = 40;  // radius for arrow placement

  u8g2.firstPage();
  do {    

    // draw radar contour
    u8g2.drawCircle(screenCenterX, screenCenterY, radarRadius-2, U8G2_DRAW_ALL);
    u8g2.drawCircle(screenCenterX, screenCenterY, radarRadius-3, U8G2_DRAW_ALL);
    u8g2.drawCircle(screenCenterX, screenCenterY, radarRadius+2, U8G2_DRAW_ALL);
    u8g2.drawCircle(screenCenterX, screenCenterY, radarRadius+3, U8G2_DRAW_ALL);
   
    // Process each object
    for(int i = 0; i < doc.size(); i++) {
      JsonObject obj = doc[i];

      // check that the istances are of the specified class      
      if(obj["class"] != MenuBitmaps::object_tipes[screenMenuL.getSelectedItem()])
        continue;
     
      // Get object center in image coordinates
      long objX = obj["center"][0];
      long objY = obj["center"][1];
      
      // Convert to screen coordinates relative to center
      int relativeX = ((objX * SCREEN_WIDTH) / IMG_WIDTH) - screenCenterX;
      int relativeY = ((objY * SCREEN_HEIGHT) / IMG_HEIGHT) - screenCenterY;
      
      // Calculate angle using atan2 (returns radians)
      float angle = atan2(relativeY, relativeX);
      
      // Calculate arrow position on circumference
      int arrowX = screenCenterX + (int)(cos(angle) * radarRadius);
      int arrowY = screenCenterY + (int)(sin(angle) * radarRadius);
      
      // Optional: Add distance indication with different arrow sizes
      float distance = sqrt(relativeX*relativeX + relativeY*relativeY);

      // Based on the distance from the center
      if(distance >= radarRadius - 5){
        // Draw directional arrow
        drawDirectionalArrow(arrowX, arrowY, angle, (SCREEN_HEIGHT - distance)/3);
      }else{
        // Draw the precise location
        long x = (objX * SCREEN_WIDTH) / IMG_WIDTH;
        long y = (objY * SCREEN_HEIGHT) / IMG_HEIGHT;
      
        drawCenterCross(x, y);
      }
    }
   
  } while (u8g2.nextPage());
}

void drawCenterCross(long centerX, long centerY){
  u8g2.drawLine(centerX-5, centerY-1, centerX+5,  centerY-1);
  u8g2.drawLine(centerX-5, centerY,   centerX+5,  centerY);
  u8g2.drawLine(centerX-5, centerY+1, centerX+5,  centerY+1);

  u8g2.drawLine(centerX-1, centerY-5, centerX-1,  centerY+5);
  u8g2.drawLine(centerX,   centerY-5, centerX,    centerY+5);
  u8g2.drawLine(centerX+1, centerY-5, centerX+1,  centerY+5);
}

// Function to draw directional arrow pointing outward
void drawDirectionalArrow(int x, int y, float angle, int arrowSize) {  
  // Calculate arrow tip (pointing in the direction of the object)
  int tipX = x + (int)(cos(angle) * arrowSize);
  int tipY = y + (int)(sin(angle) * arrowSize);
  
  // Calculate arrow base points (perpendicular to direction)
  float perpAngle1 = angle + 2.356; // angle + 135 degrees in radians
  float perpAngle2 = angle - 2.356; // angle - 135 degrees in radians
  
  int baseX1 = x + (int)(cos(perpAngle1) * (arrowSize/2));
  int baseY1 = y + (int)(sin(perpAngle1) * (arrowSize/2));
  
  int baseX2 = x + (int)(cos(perpAngle2) * (arrowSize/2));
  int baseY2 = y + (int)(sin(perpAngle2) * (arrowSize/2));
  
  // Draw the arrow triangle
  u8g2.drawTriangle(tipX, tipY, baseX1, baseY1, baseX2, baseY2);
}

void DrawMenu(){
  int item_selected = screenMenuL.getSelectedItem();
  int item_previous = screenMenuL.getPreviousItem();
  int item_next = screenMenuL.getNextItem();

  // count all the istances of the specified class and prepare visualization string
  int objCount = CountClassObjects(MenuBitmaps::object_tipes[screenMenuL.getSelectedItem()]);
  String foundInfo = "Found " + String(objCount);

  u8g2.firstPage();
  do {    
    u8g2.setBitmapMode(1);  // set drawing mode to "combine" the bitmaps
    
    // === draw the interface elements ===
    // - dashboard (to fit the classes icons)
    u8g2.drawXBMP(40, 33, 48, 48, MenuBitmaps::epd_bitmap_dashboard);

    // - scrollbar (to show the progression in the classes list)
          int scrollbarPos = 5 + ((128/MenuBitmaps::ICON_COUNT) * item_selected);
    u8g2.drawXBMP(0, 6, 128, 8, MenuBitmaps::epd_bitmap_scrollbar);
    u8g2.drawXBMP(scrollbarPos, 6, 24, 8, MenuBitmaps::epd_bitmap_scrollbar_handle);

    // === fill the interface
    // - with the actual selected class
    // - and the previos and next one
    u8g2.drawXBMP(6, 42, 32, 32, MenuBitmaps::icon_bitmaps[item_previous]);
    u8g2.drawXBMP(49, 42, 32, 32, MenuBitmaps::icon_bitmaps[item_selected]);
    u8g2.drawXBMP(92, 42, 32, 32, MenuBitmaps::icon_bitmaps[item_next]);

    // - draw the number of istance for the selected class
    u8g2.setFont(u8g2_font_crox5hb_tf);
    u8g2.drawStr(18, 110, foundInfo.c_str());
    
    u8g2.setBitmapMode(0); // set drawing mode to normal

  } while (u8g2.nextPage());
}

int s = 0;
void DrawStatus(String msg){
  u8g2.firstPage();
  do {        
    u8g2.drawXBMP(52, 45, 24, 24, MenuBitmaps::load_bitmaps[s]);

    u8g2.setFont(u8g2_font_crox5hb_tf);
    u8g2.drawStr(16, 110, msg.c_str());
  } while (u8g2.nextPage());

  s++;
  if(s >= 2)
    s = 0;
}

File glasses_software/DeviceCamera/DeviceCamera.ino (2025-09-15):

#include "esp_camera.h"
#include "CameraConf.h"
#include <WiFi.h>
#include <HTTPClient.h>

const char* ssid = "AndroidOp";
const char* password = "certosino";
const char* serverURL = "http://192.168.43.5:5000/upload";  // Replace with your PC's IP

// baud rate info
# define BR_COMUNICATION 9600 // to talk with ArduinoNano 
# define BR_DEBUG 115200      // to check device outputs

camera_fb_t * fb = NULL;

void setup() {
  Serial1.begin(BR_COMUNICATION, SERIAL_8N1, 1, 3);
  Serial.begin(BR_DEBUG);

  // definizione parametri configurazione camera  
  camera_config_t config = createCameraConf();

  // inizializzazione della camera con la configurazione definita
  esp_err_t err = esp_camera_init(&config);
  if (err != ESP_OK) {
    Serial.printf("Camera init failed with error 0x%x", err);
    return;
  }

  // connessione al wifi
  WiFi.begin(ssid, password);
  while (WiFi.status() != WL_CONNECTED) {
    delay(500);
    Serial1.println("connect");
    Serial.print(".");
  }
  Serial.println("");

  // se la connessione è andata a buon fine debug
  Serial.println("WiFi connected!");
  Serial.print("IP address: ");
  Serial.println(WiFi.localIP());
}

void captureImage() {
  // catturo frame dalla camera
  fb = esp_camera_fb_get();
  if(!fb) {
    Serial.println("Camera capture failed");
    return;
  }
}
void captureClean() {
  esp_camera_fb_return(fb);
}

void sendImageToPython() {
  // [ ->] === stato ===  
  // preparo il "paccetto" con il frame per l'invio
  HTTPClient http;
  http.begin(serverURL);
  http.addHeader("Content-Type", "image/jpeg");
  
  // [<->] === stato ===
  // invio il "pacchetto" e ottengo la "risposta"
  int httpResponseCode = http.POST(fb->buf, fb->len);
  
  // [<- ] === stato ===
  // controllo se la cominicazione è andata a buon fine

  if(httpResponseCode > 0) {
    String response = http.getString();    
    
    Serial.println("HTTP Response: " + String(httpResponseCode));
    Serial.println("HTTP Response: " + response);
    Serial1.println(response);

  } else {
    Serial1.println("com_err");
    Serial.println("Error sending POST request");
  }
  
  http.end();
}

void loop() {
  captureImage();
  sendImageToPython();
  captureClean();
}

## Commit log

2025-08-12 aggiunti file di prova per flusk server
2025-08-14 test camera conf split
2025-08-14 invio verso arduino e visualizzazione delle info trovate da esp
2025-08-18 rifiniti settaggi prestazioni camera
2025-09-15 ristrutturazione codice, problemi latenza
    [CameraConf.h, DeviceCamera.ino, DeviceScreen.ino]
2025-09-15 aggiunta file scorso commit
    [DBZ_Scouter_No_padding_or_earhook.stl]
